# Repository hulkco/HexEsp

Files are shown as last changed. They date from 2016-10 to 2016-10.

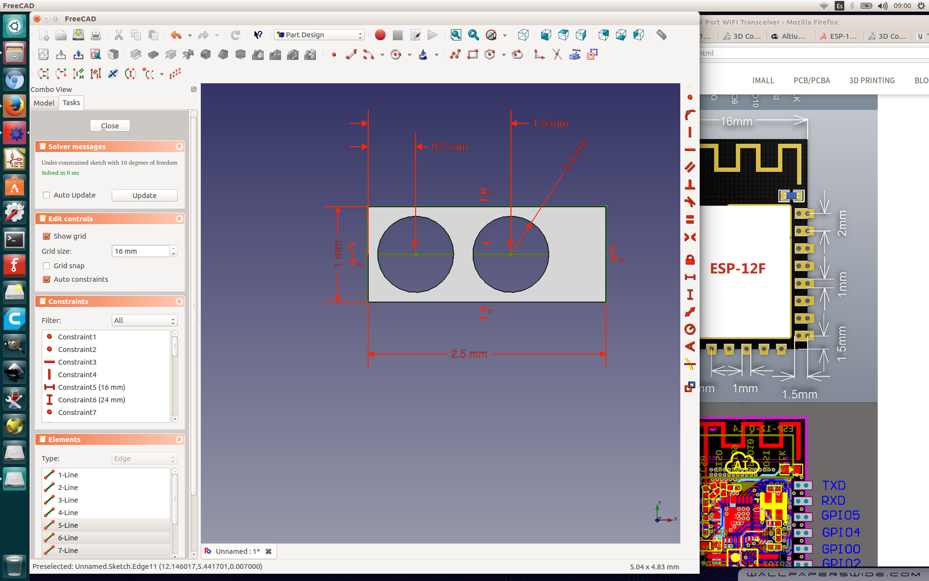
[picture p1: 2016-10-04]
ch340/images/Taladro-Esp-12f.png

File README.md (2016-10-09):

# HexEsp is a Breakout Board of amazing ESP8266 in a nice Hexagon PCB.

First thank you for visiting my project, I tell them that I'm not an electronics engineer, I'm just an amateur (passionate) the maker movement, and this is the second board that I make, I am supporting the designs of @Adafruit and @NodeMCU.

Following the philosophy of Open Software and Hardaware and the teachings of Master @Obijuan_cube, published under the Free license.

ch340 directory include a  ch340g Serial-Uart version of HexEsp
cp2104 directory include a  cp2104 Serial-Uart version of HexEsp

License
=======

GPL license or Creative Commons Attribution-shareAlike  (Copyleft)

Authors
=======
* Gustavo Salvador Reynaga Aguilar

Credits
=======
Espressif
Adafruit
NodeMCU

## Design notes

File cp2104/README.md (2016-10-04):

# HexEsp is a Breakout Board of amazing ESP8266 in a nice Hexagon PCB.

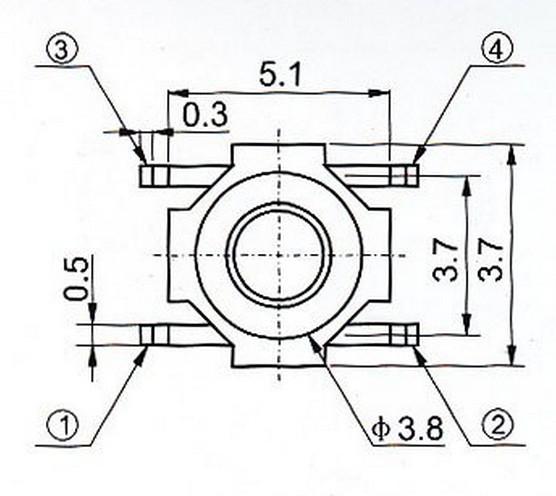
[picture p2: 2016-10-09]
ch340/images/SW/1.0x0.jpg

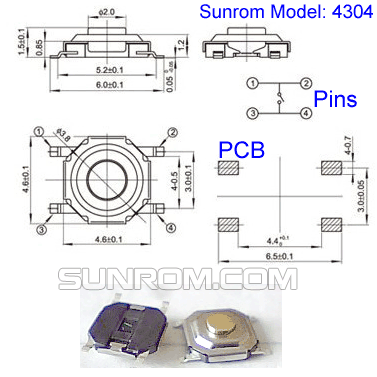
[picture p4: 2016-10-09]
ch340/images/SW/dim.gif

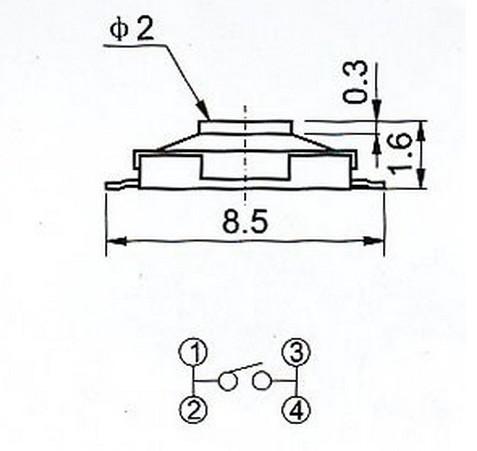
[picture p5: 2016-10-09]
ch340/images/SW/1.0x0_02.jpg

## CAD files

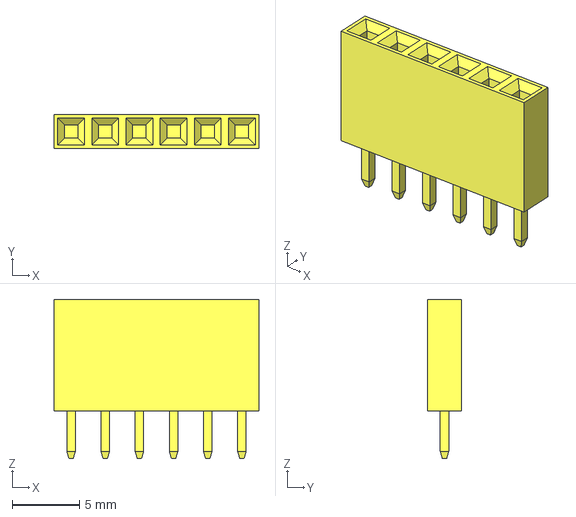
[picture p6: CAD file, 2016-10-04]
ch340/3D/1x6-female-header-blue.fcstd
15.2 x 2.54 x 11.8 mm

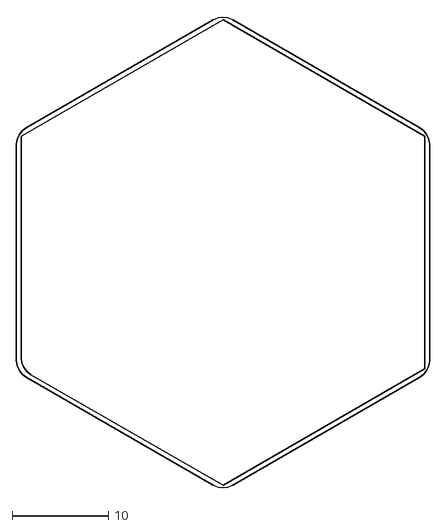
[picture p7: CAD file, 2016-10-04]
ch340/Board/HexEsp-001.dxf
43.0 x 49.2

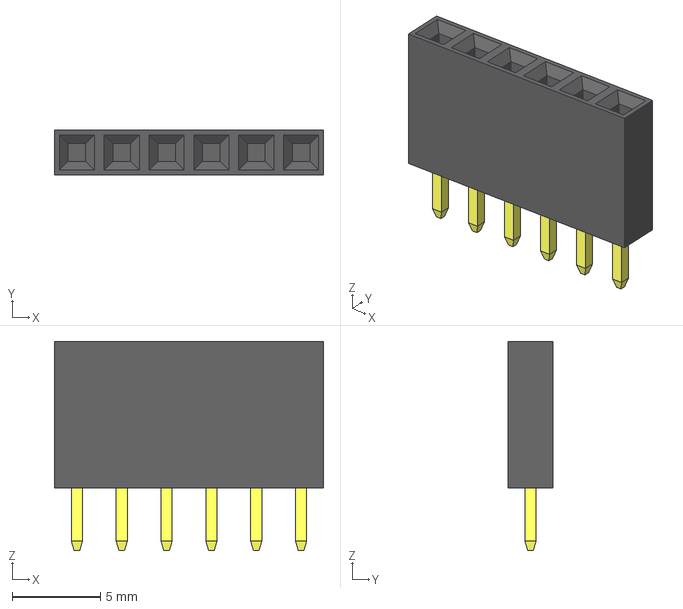
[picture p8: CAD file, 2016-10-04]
cp2104/3D/1x6-female-header-black.fcstd
15.2 x 2.54 x 11.8 mm
pin-array
1x6-female-body

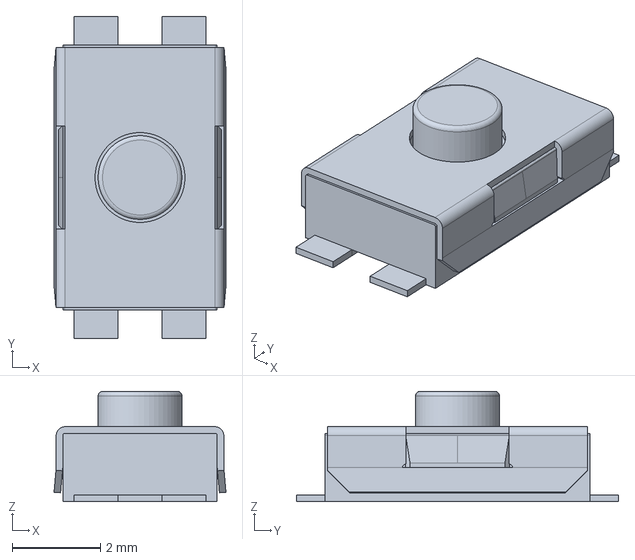
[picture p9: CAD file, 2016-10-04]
ch340/3D/SW-SMD.fcstd
3.90 x 7.30 x 2.50 mm

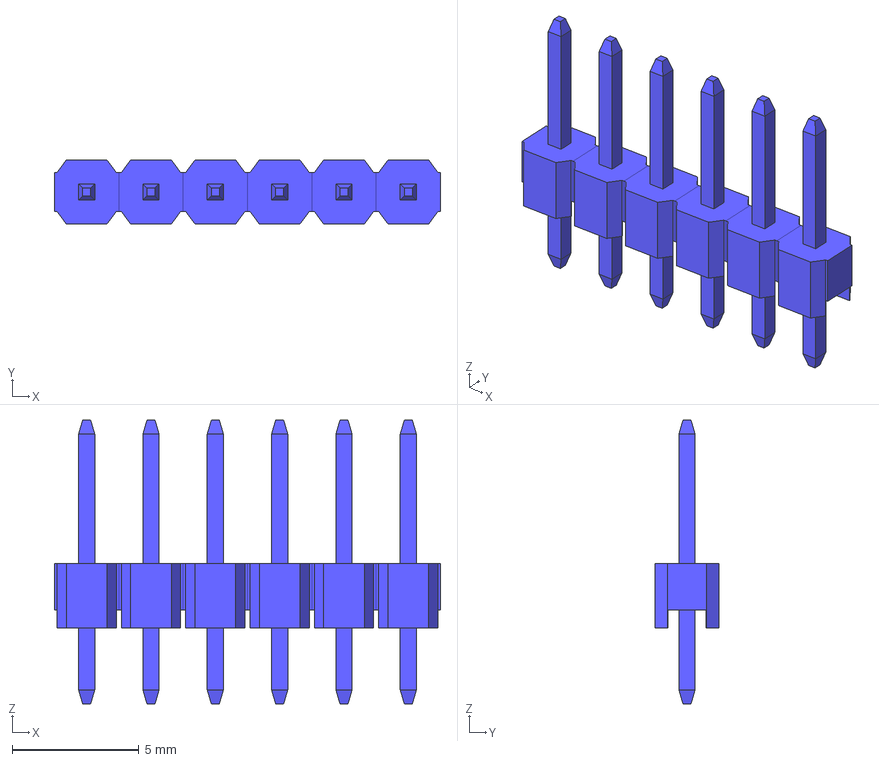
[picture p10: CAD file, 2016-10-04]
ch340/3D/1x6-male-pin-header-blue.fcstd
15.2 x 2.54 x 11.2 mm

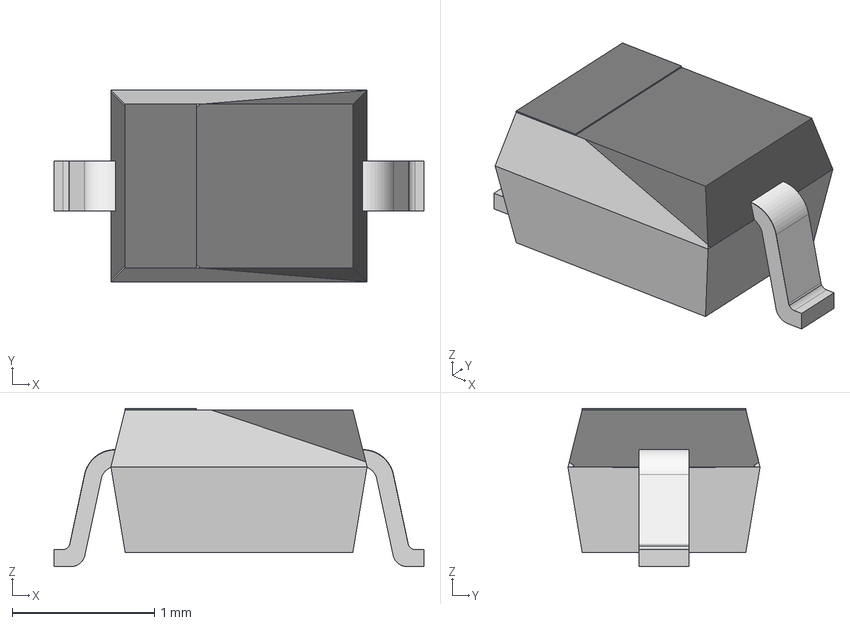
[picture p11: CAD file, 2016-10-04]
ch340/3D/SOP-123.fcstd
2.60 x 1.35 x 1.11 mm
pins001
body-loft
SOD-324

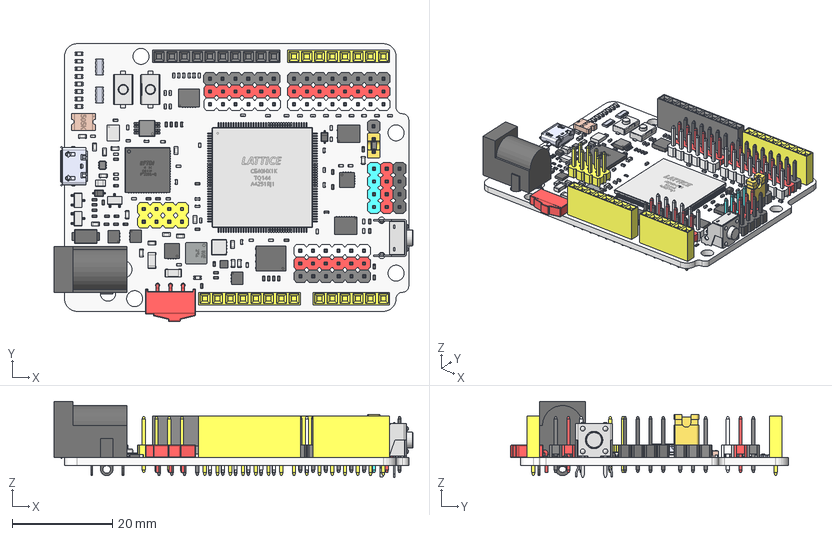
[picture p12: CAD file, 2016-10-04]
cp2104/3D/icezum.FCStd
71.5 x 55.3 x 15.2 mm
Pcb
LED_0603_
LED_0603_001
LED_0603_002
LED_0603_003
LED_0603_004
LED_0603_005
LED_0603_006
LED_0603_007
sw_smd_6.0x3.8_
sw_smd_6.0x3.8_001
LED_0603_008
R_Array_4x0603_
R_Array_4x0603_001
PVQFN20_
PVQFN20_001
1x10-socket-header_
1x6-pin-header_
1x6-pin-header_001
1x6-male-pin-header-gray_
1x6-male-pin-header-gray_001
1x6-male-pin-header-red_
1x6-male-pin-header-red_001
1x8-socket-header_
1x8-male-pin-header_
1x8-male-pin-header-red_
1x8-male-pin-header-gray_
1x8-socket-header_001
1x6-socket-header_
1x4-male-pin-header_
1x4-male-pin-header-red004_
1x4-male-pin-header-cyan_
2x4-pin-header-yello_
USB-micro-B_
jack_DC_2.1mm_PCB_
slide-sw-right-angle_
F1812-505k_
xtal-3_2x2_5_
MSOP-8_
SOT-563_
SOT23-3_
SOT23-3_001
SOT23-3_002
SOD-323_
DO-214AC_
DFN-2523-6_
DFN-2523-6_001
FTDI-QFN-64_
QFN16_
QFN16_001
L_4040_
PVQFN16_
DFN-2523-6_002
TQFP-144_
DFN-3030-8_
WSON-6_
SOD-323_001
DFN-8-6x5mm_
pushbutton-right-angle_
L_0603_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

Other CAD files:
cp2104/3D/1x6-female-pin-header.fcstd
cp2104/3D/1x6-male-pin-header-yellow.fcstd
ch340/3D/1x6-female-pin-header.fcstd
ch340/3D/1x6-female-header-yellow.fcstd
ch340/3D/1x6-male-pin-header-yellow.fcstd
cp2104/3D/1x6-female-header-red.fcstd
ch340/3D/1x6-female-header-red.fcstd
ch340/3D/1x6-male-pin-header-red.fcstd
ch340/3D/1x6-male-pin-header.fcstd
ch340/3D/SMD-RESONATOR.fcstd
ch340/3D/SW-SMD.obj
cp2104/3D/1x6-female-header-yellow.fcstd
cp2104/3D/1x6-male-pin-header-red.fcstd
cp2104/3D/1x6-male-pin-header.fcstd
cp2104/3D/SMD-RESONATOR.fcstd
cp2104/3D/SW-SMD.obj

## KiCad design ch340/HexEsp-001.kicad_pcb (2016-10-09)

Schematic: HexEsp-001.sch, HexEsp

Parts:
C1, C2, C4: 10uF; C_0805
C3: 1uF; C_0805
C5, C6: 100nF; C_0805
D1: PURPLE; LED_1206
D2: MBR120; SOD-123
IC1: CH340G; SOP-16
J1, J2, J3, J4: 1x6_female_pin_Header_2.54mm; 1x6-Socket-header-2.54mm
Q1, Q2: PZT2222A; AB2_SOT23-3
R1, R2, R4, R5: 10K; R_0805
R3, R6, R7, R8: 1K; R_0805
R9, R10: 470; R_0805
RES1: AB2_RES_3P; murata-resonator_SMD_CSTCE8M00G55-R0
SW1: RESET; SW_SPST_B3U-1000P-B
U1: ESP-12E
U2: SPX3819; AB2_SOT23-5
U3: MICRO-B_USB; USB_Micro-B

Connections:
+3V3: C2.1, C3.1, D1.2, J2.2, J4.4, R2.1, R6.2, R7.2, U1.8, U2.5
/ADC: J1.5, U1.2
/CH_PD: J1.4, R7.1, U1.3
/D+: IC1.5 (D+), U3.3
/D-: IC1.6 (D-), U3.2
/DTR: IC1.13 (DTR), Q1.3, R5.2
/EN: R1.2, U2.3
/GPIO0: J3.2, Q1.2, R3.1, U1.18
/GPIO2: J3.1, R6.1, U1.17
/GPIO4: J3.3, U1.19
/GPIO5: J3.4, U1.20
/GPIO12: J2.5, U1.6
/GPIO13: J2.4, U1.7
/GPIO14: J2.6, U1.5
/GPIO15: J4.6, R8.2, U1.16
/GPIO16: J1.3, U1.4
/RESET: J1.6, Q2.2, R2.2, U1.1
/RTS: IC1.14 (RTS), Q2.3, R4.2
/RXD: J3.5, R9.1, U1.21
/TXD: J3.6, R10.1, U1.22
/XI: IC1.7 (XI), RES1.1
/XO: IC1.8 (XO), RES1.3
GND: C1.2, C2.2, C3.2, C4.2, C5.2, C6.2, IC1.1 (GND), J2.3, J4.5, R8.1, RES1.2, U1.15, U2.2, U3.5
unnamed: C5.1, IC1.4 (V3)
unnamed: D1.1, R3.2
unnamed: IC1.2 (TXD), R9.2
unnamed: IC1.3 (RXD), R10.2
unnamed: Q1.1, R4.1
unnamed: Q2.1, R5.1
VBUS: C1.1, C4.1, C6.1, D2.1, D2.2, IC1.16 (VCC), J2.1, J4.1, R1.1, U2.1, U3.1

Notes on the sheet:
POWER AND FILTERING
USB TO UART
RESET & AUTORESET
ESP8266 CORE
LED
PINOUT

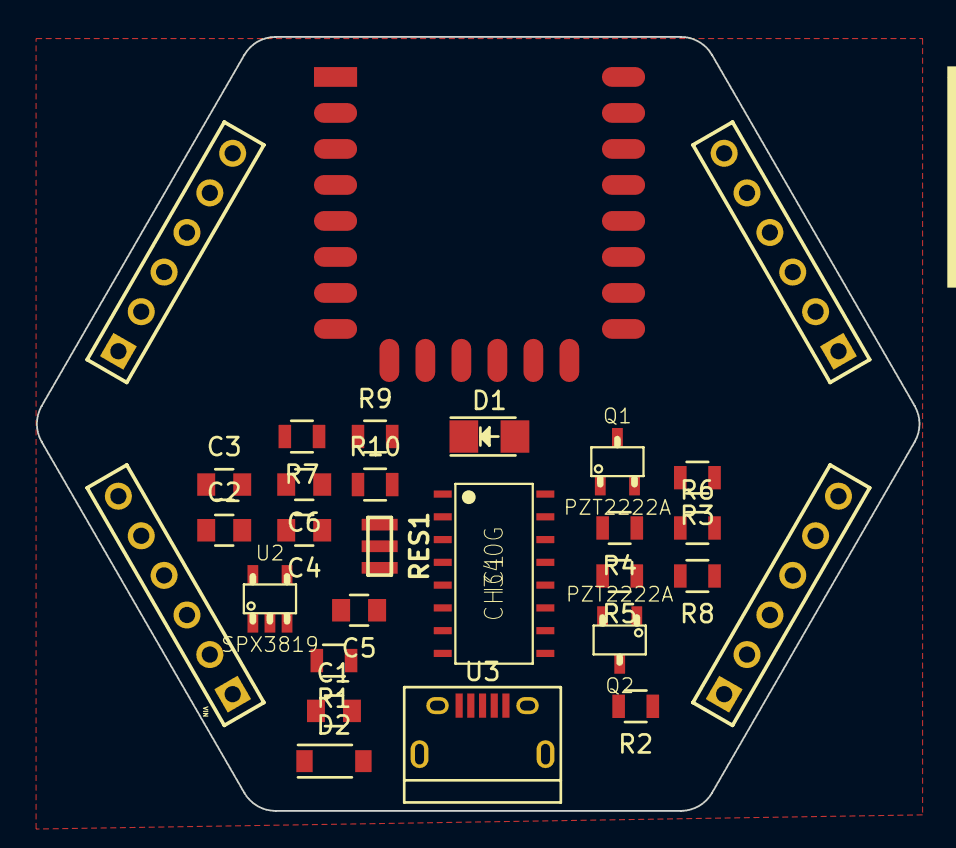
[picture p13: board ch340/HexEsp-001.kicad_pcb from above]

Board: 2 copper layers, 49.0 x 43.0 mm, 29 parts (0 on the bottom side), 30 nets.

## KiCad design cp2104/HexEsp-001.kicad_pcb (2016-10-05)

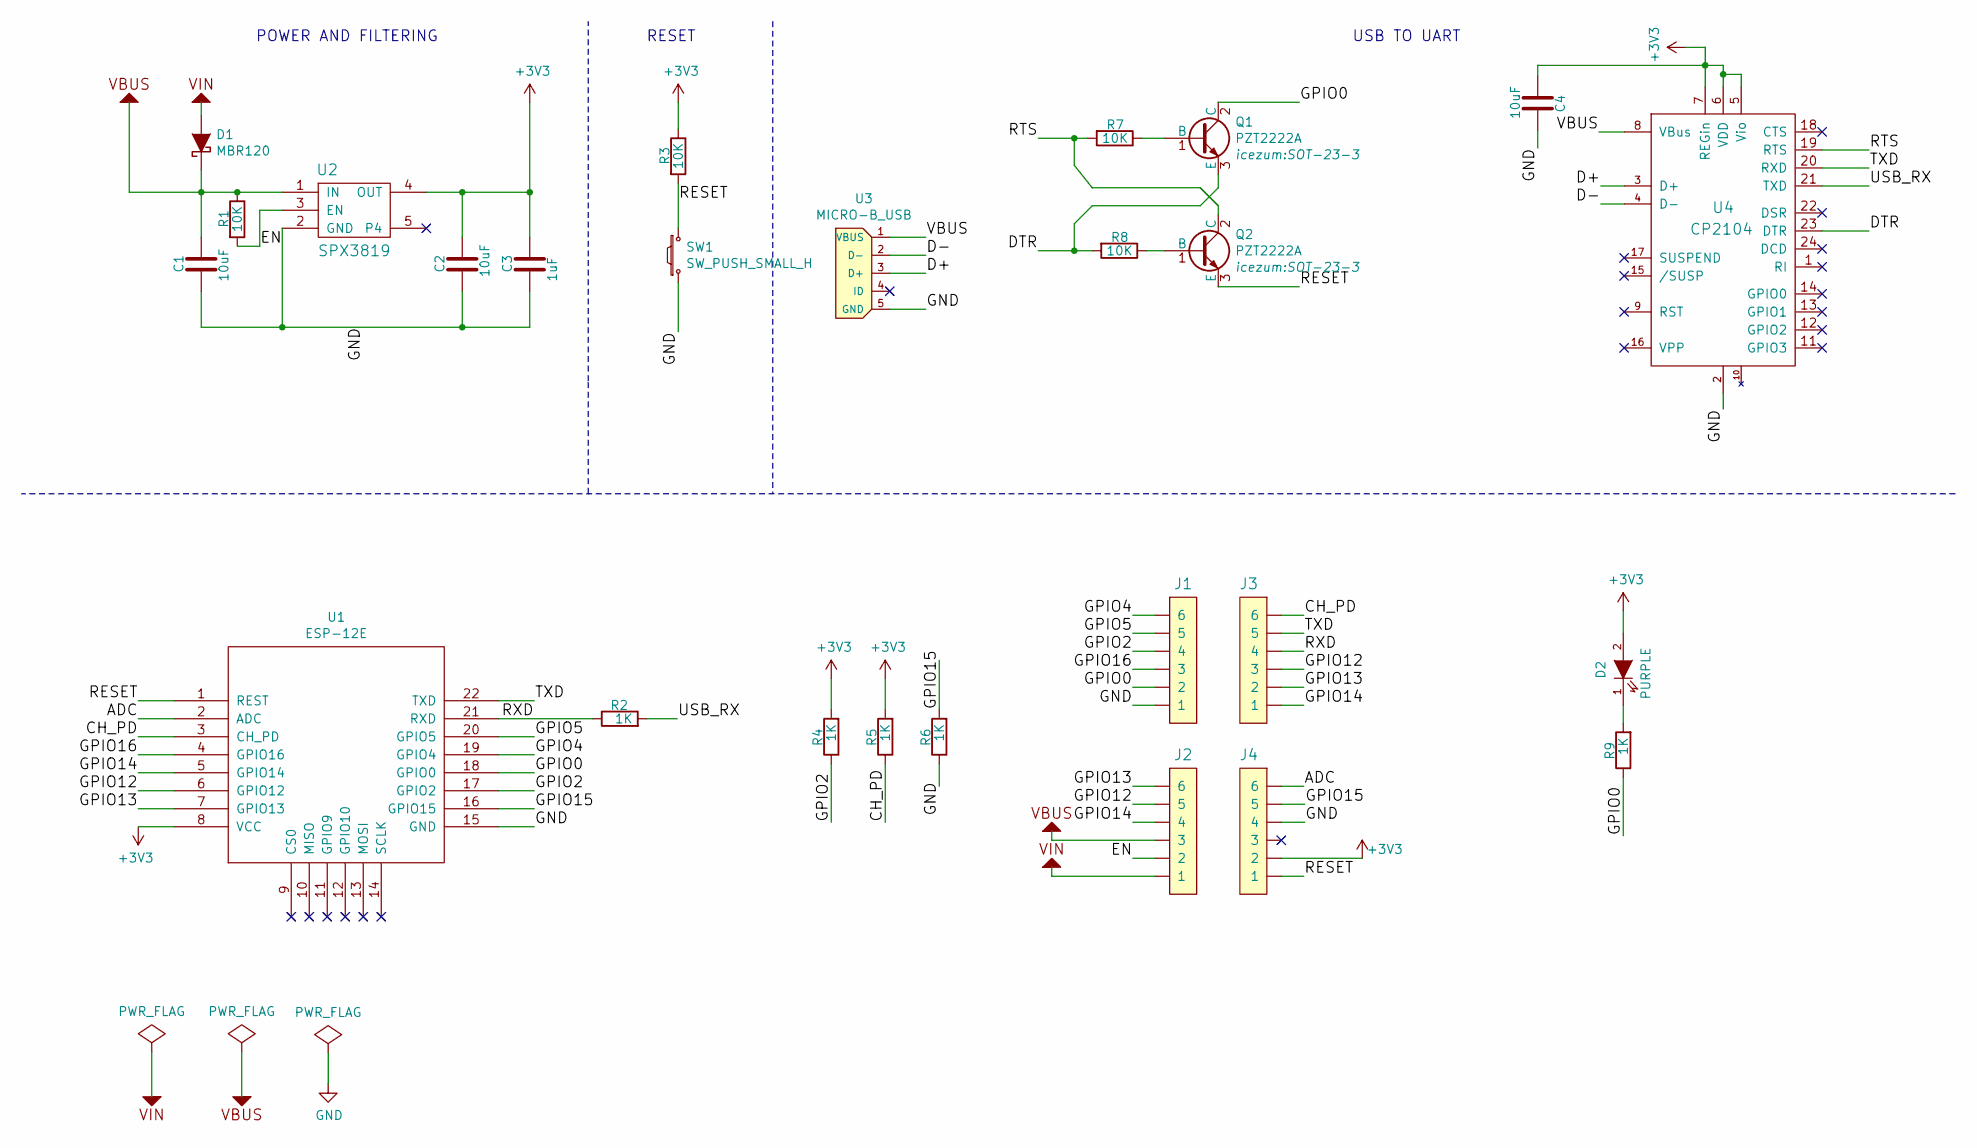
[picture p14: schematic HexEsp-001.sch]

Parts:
C1, C2, C4: 10uF; C_0805
C3: 1uF; C_0805
D1: MBR120; SOD-123
D2: PURPLE; LED_1206
J1, J2, J3, J4: 1x6_female_pin_Header_2.54mm; 1x6-Socket-header-2.54mm
Q1, Q2: PZT2222A; SOT-23-3
R1, R3, R7, R8: 10K; R_0805
R2, R4, R5, R6, R9: 1K; R_0805
SW1: SW_PUSH_SMALL_H; SW_SPST_B3U-1000P-B
U1: ESP-12E
U2: SPX3819; AB2_SOT23-5
U3: MICRO-B_USB; USB_Micro-B
U4: CP2104; QFN-24-1EP_4x4mm_Pitch0.5mm

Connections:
+3V3: C2.1, C3.1, C4.2, D2.2 (A), J4.2, R3.1, R4.2, R5.2, U1.8 (VCC), U2.4 (OUT), U4.5 (Vio), U4.6 (VDD), U4.7 (REGin)
/ADC: J4.6, U1.2 (ADC)
/CH_PD: J3.6, R5.1, U1.3 (CH_PD)
/D+: U3.3 (D+), U4.3 (D+)
/D-: U3.2 (D-), U4.4 (D-)
/DTR: Q1.3 (E), R8.2, U4.23 (DTR)
/EN: J2.2, R1.2, U2.3 (EN)
/GPIO0: J1.2, Q1.2 (C), R9.1, U1.18 (GPIO0)
/GPIO2: J1.4, R4.1, U1.17 (GPIO2)
/GPIO4: J1.6, U1.19 (GPIO4)
/GPIO5: J1.5, U1.20 (GPIO5)
/GPIO12: J2.5, J3.3, U1.6 (GPIO12)
/GPIO13: J2.6, J3.2, U1.7 (GPIO13)
/GPIO14: J2.4, J3.1, U1.5 (GPIO14)
/GPIO15: J4.5, R6.2, U1.16 (GPIO15)
/GPIO16: J1.3, U1.4 (GPIO16)
/RESET: J4.1, Q2.3 (E), R3.2, SW1.2, U1.1 (REST)
/RTS: Q2.2 (C), R7.2, U4.19 (RTS)
/RXD: J3.4, R2.1, U1.21 (RXD)
/TXD: J3.5, U1.22 (TXD), U4.20 (RXD)
/USB_RX: R2.2, U4.21 (TXD)
GND: C1.2, C2.2, C3.2, C4.1, J1.1, J4.4, R6.1, SW1.1, U1.15 (GND), U2.2 (GND), U3.5 (GND), U4.2
unnamed: D2.1 (K), R9.2
unnamed: Q1.1 (B), R7.1
unnamed: Q2.1 (B), R8.1
VIN: D1.2 (A), J2.1

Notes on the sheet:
POWER AND FILTERING
USB TO UART
RESET

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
Board: 2 copper layers, 26 parts (0 on the bottom side), 27 nets, no tracks yet.

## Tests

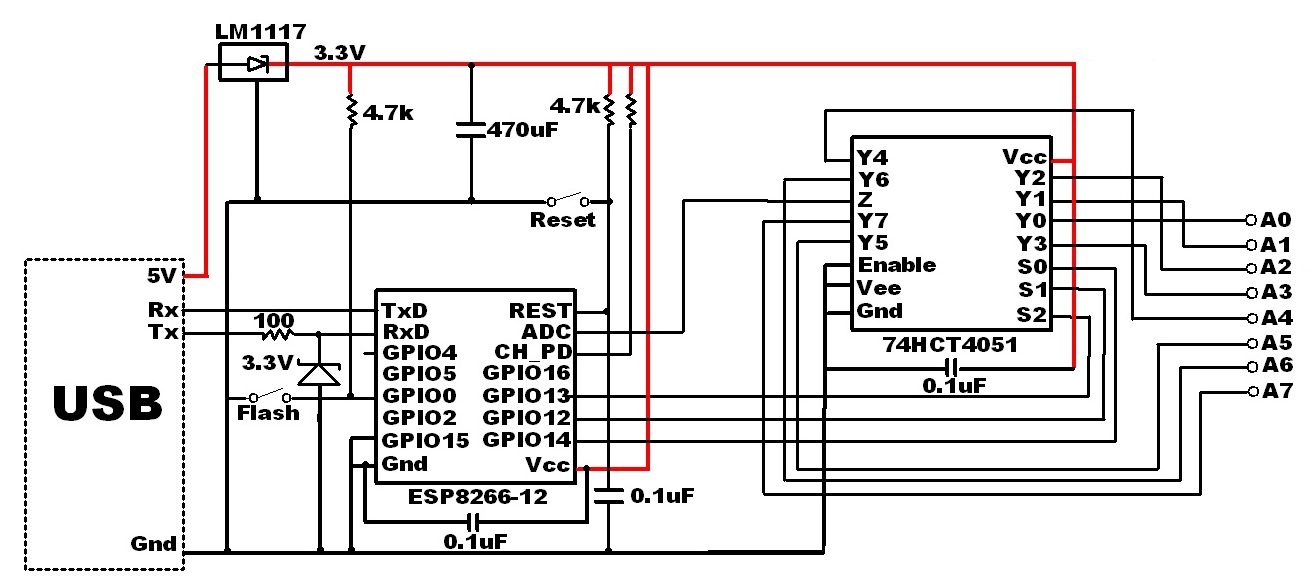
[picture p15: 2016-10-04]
cp2104/Docs/www/Internet of Home Things » 8 ESP8266 analog inputs for 22 cents_files/ESP8266-schematic-amux-test_rev1.jpg

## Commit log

2016-10-04 HexEsp Alfa Release
    [1x6-female-header-black.fcstd, 1x6-female-header-blue.fcstd, 1x6-female-header-red.fcstd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]
2016-10-05 Re-organized directory
    [1x6-female-header-black.fcstd, 1x6-female-header-blue.fcstd, 1x6-female-header-red.fcstd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]
2016-10-09 Some litle changes
    [HexEsp-001.kicad_pcb, HexEsp-001.sch]
